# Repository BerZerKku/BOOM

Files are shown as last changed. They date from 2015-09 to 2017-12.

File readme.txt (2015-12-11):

Boom

BOOM-LCD_01v1
Плата индикации для проекта BOOM.

BOOM-MCU_01v1
Плата управления для проекта BOOM.
Разъем X2 установлен не с той стороны платы, пока запаян шлейф. 
Нужны доработки по входам Wire (подтяжка к +5В и кондер на землю).
Кнопки S1,S2 установлены выводные на стороне TOP.
Почему-то не совпали номера сегментов при выводе значений на индикатор, надо проверить!

PHONE-CODE_01v1
Плата управления для телефона.
Питание на плате появляется при снятой трубке.
Вводится номер. Если верный, то подается сигнал управления (замыкание на змелю, 2А, 30В). Сигнал управления подается 1 минуту или до момента возвращения трубки на место. Если номер не верный, то нужно положить трубку и снять заново.

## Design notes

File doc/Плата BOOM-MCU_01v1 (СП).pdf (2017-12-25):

№ | Наименование | Корпус | Кол. | Поз. | Примечание
5 | Лист | № докум. | Подп. | Дата | BOOM-MCU_01v1 Изм
Разраб. | Щеблыкин М.В | | | Плата BOOM-MCU_01v1 Спецификация | Лит. | Лист | Листов
Провер. | | | | | | 1 | 3

Н.контр.
Утв.
1 | Сборочный чертеж
| BOOM-MCU_01v1 rev.0 | 1

ДЕТАЛИ
3 | Плата печатная
| BOOM-MCU_01v1 | 1

ПРОЧИЕ ИЗДЕЛИЯ

Диоды

5 | MBR0540 | SOD123 | 3 | VD1,VD3,VD4 | N000274990
6 | P6SMB18CA | DO-214AA | 2 | VD7,VD8 | О01301
7 | P6SMB300CA | DO-214AA | 1 | VD6 | О16069
9 | SM6T30CA | DO-214AA | 1 | VD5 | N000379801
11 | STPS160U STM | DO-214AA | 1 | VD2 | N000388908
15 | Индуктивность SCDS127T-331M-N 330u 0.95A YAGEO | SMD_2 | 1 | L1 | промка
16 | Индуктивность LQH43CN100K 650mA 10uH 10% 1812 MURATA | SMD_2 | 1 | L2*

Конденсаторы

19 | 0805 NP0 50V 22pF 5% | 0805 | 2 | C8,C9 | О05537
20 | 0805 X7R 50V 0.01uF 10% | 0805 | 3 | C13*,C14*,C15* | О03660
21 | 1206 X7R 50V 0.1uF 10% | 1206 | 6 | C1,C3-C5,C7,C16* | О01782
23 | 1206 X7R 50V 1uF 10% | 1206 | 2 | C10,C12,C17* | О12148
25 | 1206 X7R 25V 10uF 10% | 1206 | 1 | С2 | N000381052
27 | тантал 10V 220uF 10% X | X | 2 | C6*,C11 | N000309836
31 | Кварцевый резонатор KX-3H
16.0MHz HC-49/S GEYER | 2 pins | 1 | ZQ1 | О00314

| | | | | BOOM-MCU_01v1 | Лист
5 | | | | | | 2
Изм | Лист | № докум. | Подп. | Дата
35 | Крышка 255-600 WAGO | 3 | N000197881

Микросхемы

39 | AT90USB162-16AU ATMEL | TQFP32 | 1 | DD1 | ОS1761
41 | G3VM-351E OMRON | SMD_6 | 2 | U2,U3 | N000367341
43 | HCPL-817-300E AVAGO | SMD_4 | 1 | U1 | N000389177
45 | LM2574M-5.0 TI | SOIC_14 | 1 | DA1 | О05934
49 | Переключатель SWT-20-4,3 | 4 pins | 2 | S1*,S2* | О00616
53 | Предохранитель MF-SM75/60
самовосст. BOURNS | SMD_2 | 1 | F1 | N000428722

Разъемы

57 | 255–401 Gray WAGO | 2 pins | 7 | J2,J4,J6,J8,J9,J11,J13 | N000246172
59 | 255–746 Orange WAGO | 2 pins | 7 | J1,J3,J5,J7,J10,J12,J14 | N000246339
61 | PBD-20 | 20 pins | 1 | X2 | О00425 Не устанавл.
63 | USB A 18 вилка SMT | 6 pins | 1 | X1 | N000334100

Резисторы

65 | 0805 3.6 5% | 0805 | 3 | R3* | О00024
65 | 0805 10K 5% | 0805 | 3 | R31*,R32*,R33* | О00029
67 | 1206 24 5% (1206 24.9 1%) | 1206 | 2 | R1,R2 | N000388735 (О02250)
69 | 1206 100 5% | 1206 | 13 | R5-R16,R18 | О01268
71 | 1206 510 5% | 1206 | 2 | R19,R20 | О07691
73 | 1206 1K 5% | 1206 | 8 | R17,R21,R24-29 | О01259
75 | 1206 10K 5% | 1206 | 3 | R22,R23,R30 | О08066
79 | Феррит BLM31PG601SN1 MURATA | 1206 | 2 | FB1,FB2 | N000307145
| | | | * - доработка

| | | | | BOOM-MCU_01v1 | Лист
5 | | | | | | 3
Изм | Лист | № докум. | Подп. | Дата

Лист регистрции изменений СП
№ Изм. | № замененных (измененных) страниц | Дата ревизии | Краткое содержание и причина внесения изменений | Примечание
0 | вновь | 16.09.2015
1 | 1-2 | 11.12.2015 | Добавлены поз.20 и 65. Изменена поз.49 на выводную кнопку. Поз.61 не устанавливать.
2 | 1-2 | 12.02.2016 | Добавлена поз.6, туда перенесены 2 диода из поз.7.
3 | 1 | 17.03.2016 | В поз.21 добавлен С16*.
4 | 1-2 | 22.12.2017 | В поз.26 добавлен С6*. Поз.65 изменена на 3.6 Ом.
5 | 1 | 25.12.2017 | В поз.23 добавлен С17*. Добавлена поз.16 (L2*).

Исполнения:

Лист регистрции изменений СБ
№ Изм. | № замененных (измененных) страниц | Дата ревизии | Краткое содержание и причина внесения изменений | Примечание
0 | вновь | 16.09.2015

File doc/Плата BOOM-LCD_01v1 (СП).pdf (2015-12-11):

№ | Наименование | Корпус | Кол. | Поз. | Примечание
1 | Лист | № докум. | Подп. | Дата | BOOM-LCD_01v1 Изм
Разраб. | Щеблыкин М.В | | | Плата BOOM-LCD_01v1 Спецификация | Лит. | Лист | Листов
Провер. | | | | | | 1 | 2

Н.контр.
Утв.
1 | Сборочный чертеж
| BOOM-LCD_01v1 rev.0 | 1

ДЕТАЛИ
3 | Плата печатная
| BOOM-LCD_01v1 | 1

ПРОЧИЕ ИЗДЕЛИЯ

Диоды

5 | FYL-5013PURD1C-60 KINGBRIGHT | 2 pins | 2 | VD1,VD2 | N000375522
7 | SA23-11SRWA KINGBRIGHT | 10 pins | 4 | HG1-HG4 | промка

Конденсаторы

11 | 1206 X7R 50V 0.1uF 10% | 1206 | 1 | C1 | О01782
13 | 1206 X7R 25V 10uF 10% | 1206 | 1 | С2 | N000381052
| Микросхемы
17 | G3VM-351E OMRON | SMD_6 | 4 | U1-U4 | N000367341
19 | ULN2803ADW TI | SOIC_18 | 1 | DD1 | О06632
23 | Разъем IDC-20M вилка SMD | SMD_20 | 1 | X1 | промка

Резисторы

27 | 1206 100 5% | 1206 | 7 | R7-R13 | О01268
29 | 1206 510 5% | 1206 | 4 | R14-R17 | О07691
31 | 1206 2K 5% | 1206 | 1 | R6 | О01260

| | | | | BOOM-LCD_01v1 | Лист
1 | | | | | | 2
Изм | Лист | № докум. | Подп. | Дата

Лист регистрции изменений СП
№ Изм. | № замененных (измененных) страниц | Дата ревизии | Краткое содержание и причина внесения изменений | Примечание
0 | вновь | 16.09.2015
1 | 1 | 11.12.2015 | Поз.27 изменена на 100 Ом Поз.31 изменена на 2 кОм.

Исполнения:

Лист регистрции изменений СБ
№ Изм. | № замененных (измененных) страниц | Дата ревизии | Краткое содержание и причина внесения изменений | Примечание
0 | вновь | 16.09.2015

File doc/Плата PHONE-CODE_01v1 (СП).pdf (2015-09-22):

№ | Наименование | Корпус | Кол. | Поз. | Примечание
0 | Лист | № докум. | Подп. | Дата | PHONE-CODE_01v1 Изм
Разраб. | Щеблыкин М.В | | | Плата PHONE-CODE_01v1 Спецификация | Лит. | Лист | Листов
Провер. | | | | | | 1 | 3

Н.контр.
Утв.
1 | Сборочный чертеж
| PHONE-CODE_01v1 rev.0 | 1

ДЕТАЛИ
3 | Плата печатная
| PHOONE-CODE_01v1 | 1

ПРОЧИЕ ИЗДЕЛИЯ

Диоды

5 | FYL-5013PURD1C-60 KINGBRIGHT | 2 pins | 1 | VD4 | N000375522
7 | LL4148 | SOD80 | 2 | VD1,VD2 | ОN5384
9 | MBR0540 | SOD123 | 1 | VD3 | N000274990
11 | SM6T30A | DO-214AA | 1 | VD9 | N000398718
13 | SM6T30CA | DO-214AA | 1 | VD7 | N000379801
15 | SM6T6V8CA | DO-214AA | 1 | VD6 | О08193

Конденсаторы

19 | 1206 X7R 50V 0.1uF 10% | 1206 | 6 | C1,C2,C4,C6-C8 | О01782
21 | 1206 X7R 50V 1uF 10% | 1206 | 1 | C5 | О12148
23 | 1206 X7R 25V 10uF 10% | 1206 | 1 | С3 | N000381052
27 | Крышка 255-600 WAGO | 1 | N000197881

Микросхемы

31 | ATMega8-16AU ATMEL | TQFP32 | 1 | DD1 | О14110
33 | LM317EMP | SOT-223 | 1 | DA1 | О01278

| | | | | PHONE-CODE_01v1 | Лист
0 | | | | | | 2
Изм | Лист | № докум. | Подп. | Дата
37 | Переключатель SmWDL-02 | SMD_4 | 1 | SW1 | О01270

Разъемы

41 | 255–401 Gray WAGO | 2 pins | 4 | J1,J2,J5,J8 | N000246172
43 | 255–746 Orange WAGO | 2 pins | 3 | J3,J4,J7 | N000246339

Резисторы

47 | 1206 100 5% | 1206 | 1 | R13 | О01268
49 | 1206 510 5% | 1206 | 1 | R2 | О07691
51 | 1206 1K 5% | 1206 | 4 | R4,R9-R11 | О01259
53 | 1206 2K 5% | 1206 | 1 | R3 | О01260
55 | 1206 10K 5% | 1206 | 4 | R1,R6,R7,R14 | О08066
57 | 2010 56 5% | 2010 | 1 | R16 | N000251760
61 | Транзистор IRLML0060 IR | SOT23-3 | 1 | VT1 | N000368051

| | | | | PHONE-CODE_01v1 | Лист
0 | | | | | | 3
Изм | Лист | № докум. | Подп. | Дата

Лист регистрции изменений СП
№ Изм. | № замененных (измененных) страниц | Дата ревизии | Краткое содержание и причина внесения изменений | Примечание
0 | вновь | 22.09.2015

Исполнения:

Лист регистрции изменений СБ
№ Изм. | № замененных (измененных) страниц | Дата ревизии | Краткое содержание и причина внесения изменений | Примечание
0 | вновь | 22.09.2015

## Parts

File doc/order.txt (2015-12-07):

Используется у нас:
Название					Код 		Шт.		Наличие

Диоды
FYL-5013PURD1C-60  			N000375522	3		есть на складе
LL4148						ОN5384    	2 		есть на складе
MBR0540						N000274990	4 		есть на складе
P6SMB300CA					О16069		3 		есть на складе
SM6T30A						N000398718	1 		есть на складе
SM6T30CA					N000379801	2 		есть на складе
SM6T6V8CA					О08193 		1 		есть на складе
STPS160U					N000388908	1 		есть на складе

Индуктивности
SCDS127T-331M-N				NO			1 		заказать 10шт. (есть в промке) 

Кварцы
KX-3H 16.0MHz HC-49/S Geyer	О00314 		1 		есть на складе

Конденсаторы
0805 NP0 50V 22pF 5%		О05537    	2 		есть на складе
1206 X7R 50V 0.1uF 10%		О01782		12		есть на складе
1206 X7R 50V 1uF 10%		О12148		3 		есть на складе
1206 X7R 25V 10uF 10%		N000381052	2   	есть на складе
тантал 10V 220uF 10% X 		N000309836	1 		заказать 10 шт. (есть в промке T491X227K010AT)

Крышка 255-600 WAGO			N000197881	4 		есть на складе

Микросхемы		
AT90USB162-16AU ATMEL		ОS1761		1 		есть у меня 3шт, заказать 5шт.
ATMega8-16AU				О14110  	1 		есть на складе
G3VM-351E  					000367341	6 		есть на складе  
HCPL-817-300E				N000389177	1 		есть на складе
LM2574M-5.0 				О05934 		1 		заказать 10шт. (есть в промке)
LM317EMP					О01278 		1 		есть на складе
ULN2803ADW					О06632		1 		есть на складе

Переключатели 
DTSMW-2.0S					N000261668 	2 		заказать 20шт. (есть в промке)
SmWDL-02					О01270 		1 		на складе нет	

Предохранитель MF-SM75/60 	N000428722 	1 		заказать 20шт.

Разъемы
255–401 Gray WAGO 			N000246172 	8 		есть на складе
255–746 Orange WAGO 		N000246339 	7 		есть на складе
IDC-20M вилка SMD			NO			1 		заказать 10шт. (есть в промке)
PBD-20 						О00425 		1 		есть на складе	
USB A 18 вилка SMT 			N000334100 	1 		есть у меня 3шт, заказать 5шт.

Резисторы
1206 24.9 1%				О02250     	2 		есть на складе
1206 100 5% 				О01268 		14 		есть на складе	
1206 200 5%					О06039		7 		есть на складе
1206 510 5% 				О07691		7 		есть на складе
1206 1K 5%					О01259		13 		есть на складе
1206 1.5K 5%				О01267     	1 		есть на складе
1206 10K 5%					О08066 		7 		есть на складе	
2010 100 5%					N000400359	1 		есть на складе

Транзистор IRLML0060 		N000368051 	1 		есть на складе

Феррит BLM31PG601SN1		N000307145	2 		есть на складе

Купить самому:
Щуп BANAN б/пайки Gold тип1   	30шт. - Узнать про гнезда на панель!
Разъем MDN-6J розетка на печатную плату (AUK) 5шт.
Индикатор SA23-11SRWA			4шт.

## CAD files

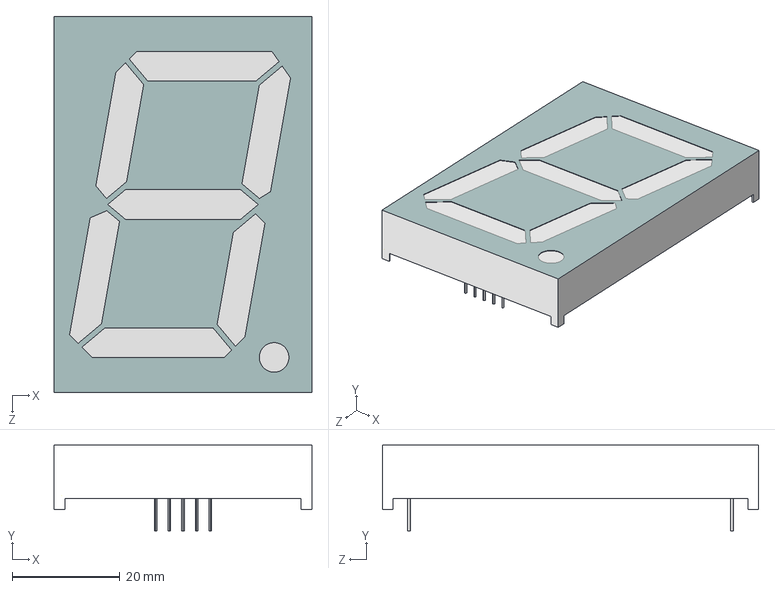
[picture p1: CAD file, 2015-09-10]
pcb-lcd/SA23-11.STEP
48.0 x 16.0 x 70.0 mm

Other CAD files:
doc/Плата BOOM_01v1 (СБ).dwg
doc/Плата BOOM-LCD_01v1 (СБ).dwg
doc/Плата BOOM-MCU_01v1 (СБ).dwg
doc/Плата PHONE-CODE_01v1 (СБ).dwg
pcb-lcd/dip254p6010x1200-10n.psm
pcb-lcd/soic127p1030x265-18n.psm
pcb-lcd/soic254p1000x1020-20n.psm
pcb-lcd/soic254p978x342-6m.psm
pcb-mcu/con_usb_a_male_smd.psm
pcb-mcu/indc12501250x800n.psm
pcb-mcu/qfp80p900x900x120-32n.psm
pcb-mcu/soic127p1032x265-14n.psm
pcb-phone/qfp80p900x900x120-32n.psm
pcb-phone/relay_32_21.psm
pcb-phone/soic254p978x342-6m.psm

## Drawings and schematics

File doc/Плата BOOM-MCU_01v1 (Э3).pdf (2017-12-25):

* - Доработка.

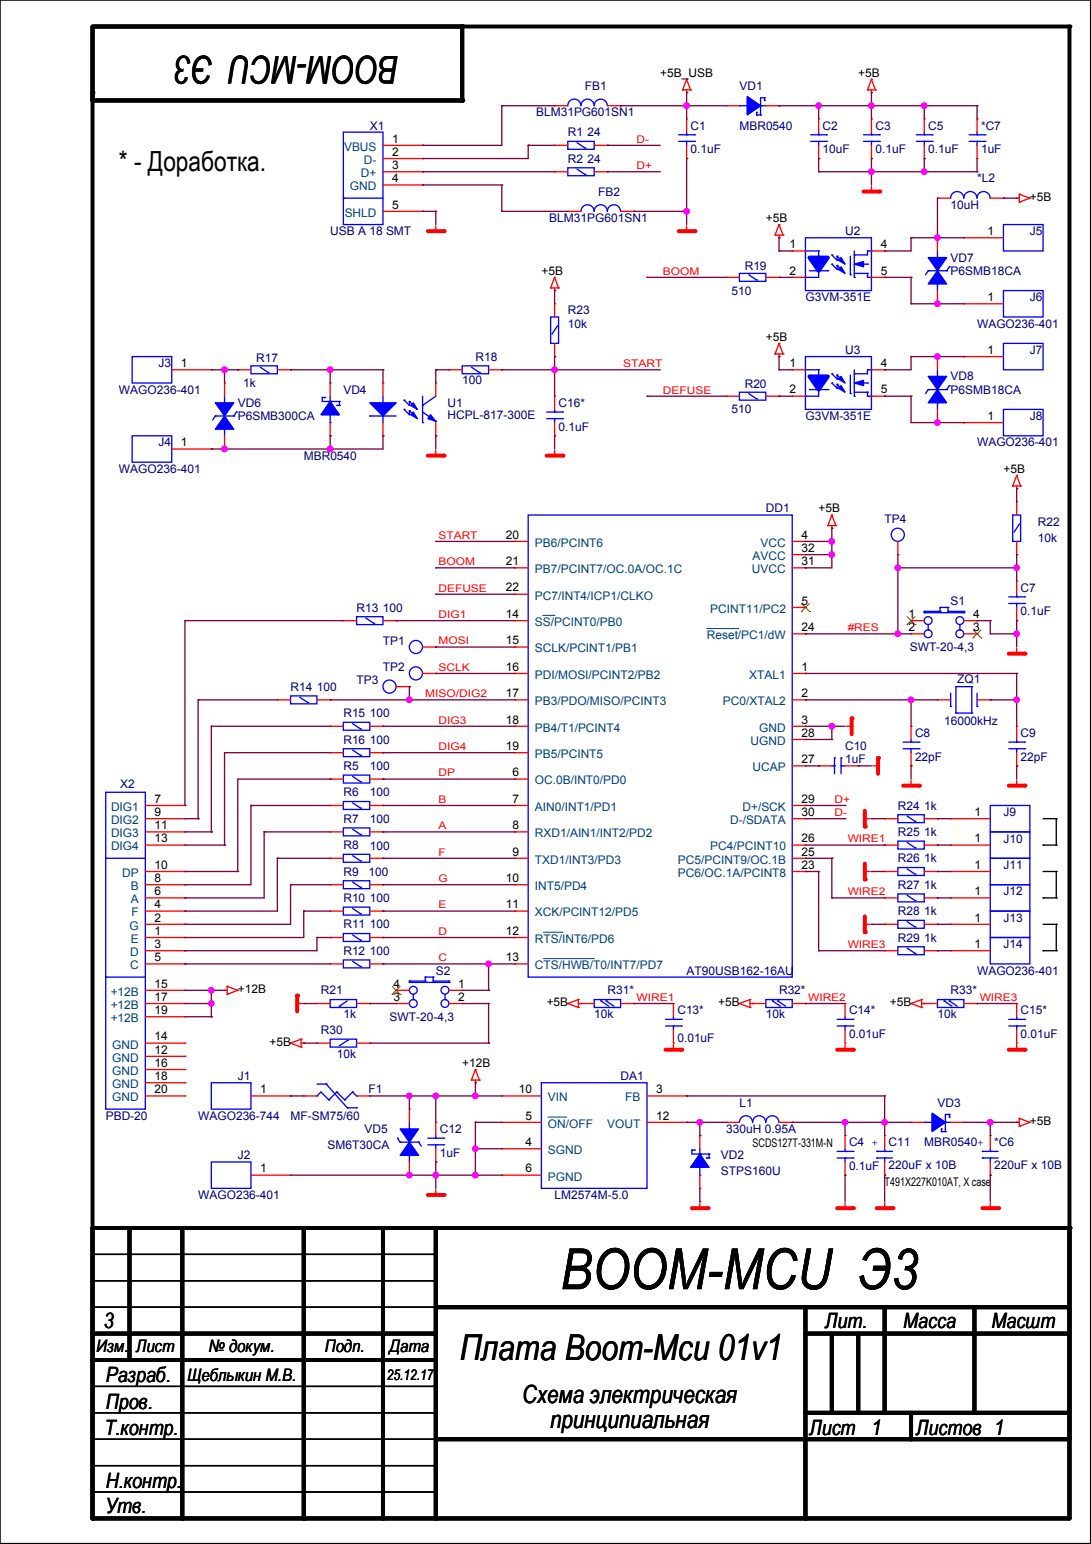
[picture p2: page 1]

BOOM-MCU Э3 BOOM-MCU Э3 BOOM-MCU Э3

3 | | | | | Плата Boom-Mcu 01v1 Плата Boom-Mcu 01v1 Плата Boom-Mcu 01v1 Схема электрическая Схема электрическая Схема электрическая | Лит. | Масса Масса Масса | Масшт Масшт Масшт
Изм. Изм. Изм. | Лист Лист Лист | № докум. № докум. № докум. | Подп. Подп. Подп. | Дата Дата Дата
Разраб. Разраб. Разраб. | | Щеблыкин М.В. Щеблыкин М.В. Щеблыкин М.В. | | 25.12.17 25.12.17 25.12.17
Пров. Пров. Пров.
принципиальная Т.контр. принципиальная Т.контр. принципиальная Т.контр. | Лист Лист Лист 1 1 1 1 1 1 | Листов Листов Листов

Н.контр. Н.контр. Н.контр.
Утв. Утв. Утв.

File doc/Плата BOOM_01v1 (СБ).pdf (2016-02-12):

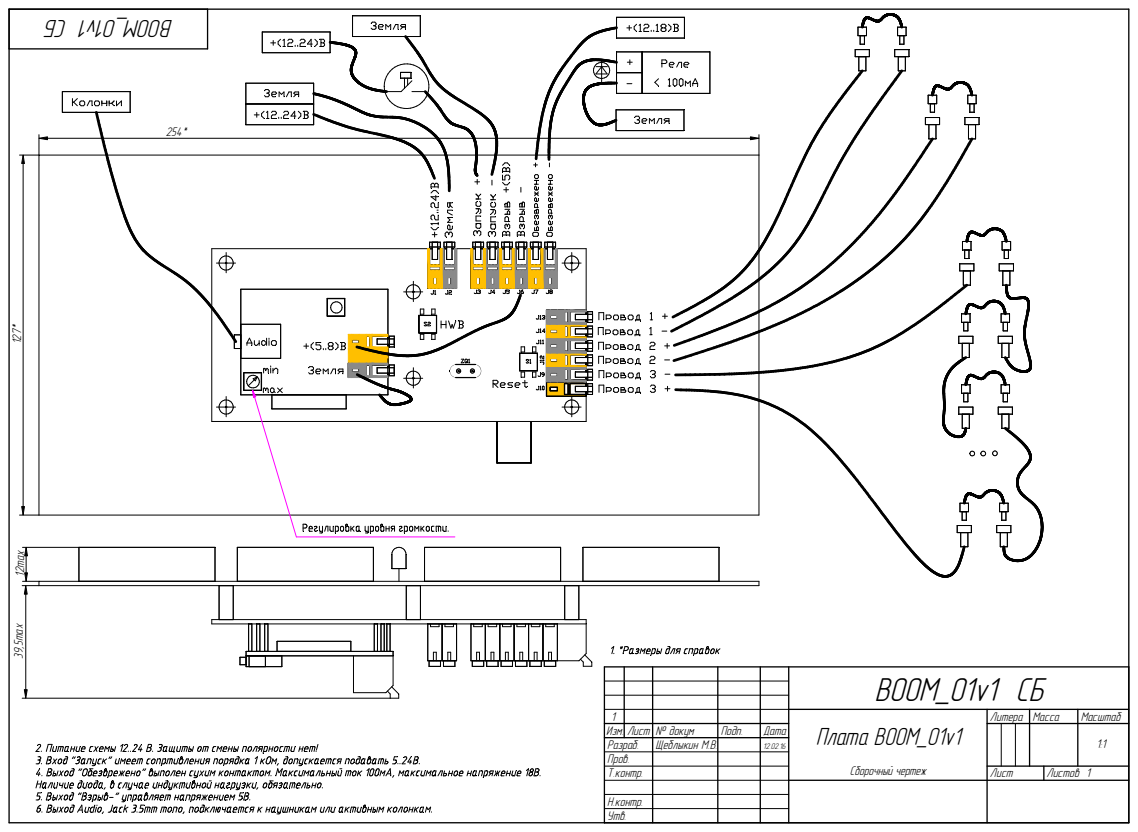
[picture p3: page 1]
12max 39,5max

BOOM_01v1 ÑÁ

1 | | | | Ïëàòà BOOM_01v1 Ñáîðî÷íûé ÷åðòåæ | Ëèòåðà | Ìàññà | Ìàñøòàá
Èçì. Ëèñò | № äîêóì | Ïîäï. | Äàòà 12.02.16 | | | | | 1:1
Ðàçðàá. | Ùåáëûêèí Ì.Â.
Ïðîâ.
Ò.êîíòð. | | | | Ëèñò | Ëèñòîâ 1

Í.êîíòð.
Óòâ.

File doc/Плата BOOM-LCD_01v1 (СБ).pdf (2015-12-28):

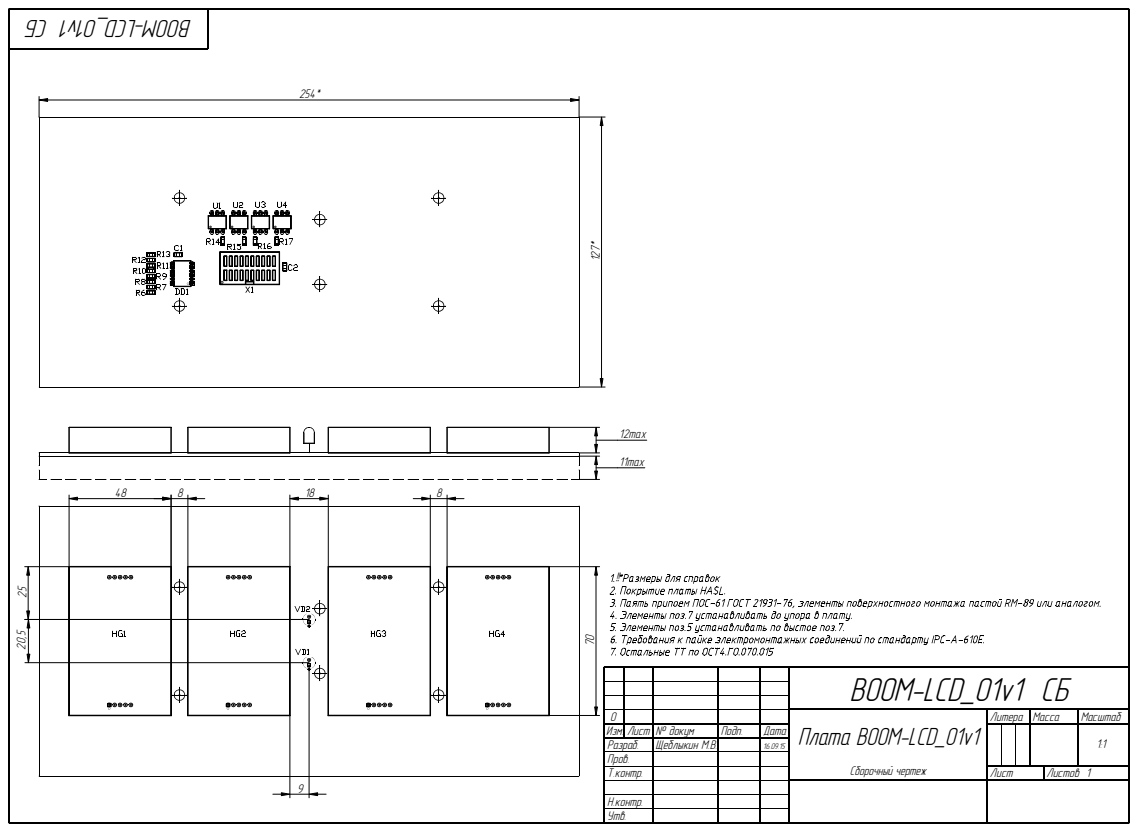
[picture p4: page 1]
Ëèñòîâ 1; Ìàññà; Ìàñøòàá; Ïîäï.; Äàòà; Óòâ.; Í.êîíòð.; Ò.êîíòð.; Ïðîâ.; Ðàçðàá.; Èçì. Ëèñò; Ùåáëûêèí Ì.Â.; № äîêóì; Ëèñò; Ëèòåðà; Ïëàòà BOOM-LCD_01v1; BOOM-LCD_01v1 ÑÁ; 11max; 12max

Ñáîðî÷íûé ÷åðòåæ

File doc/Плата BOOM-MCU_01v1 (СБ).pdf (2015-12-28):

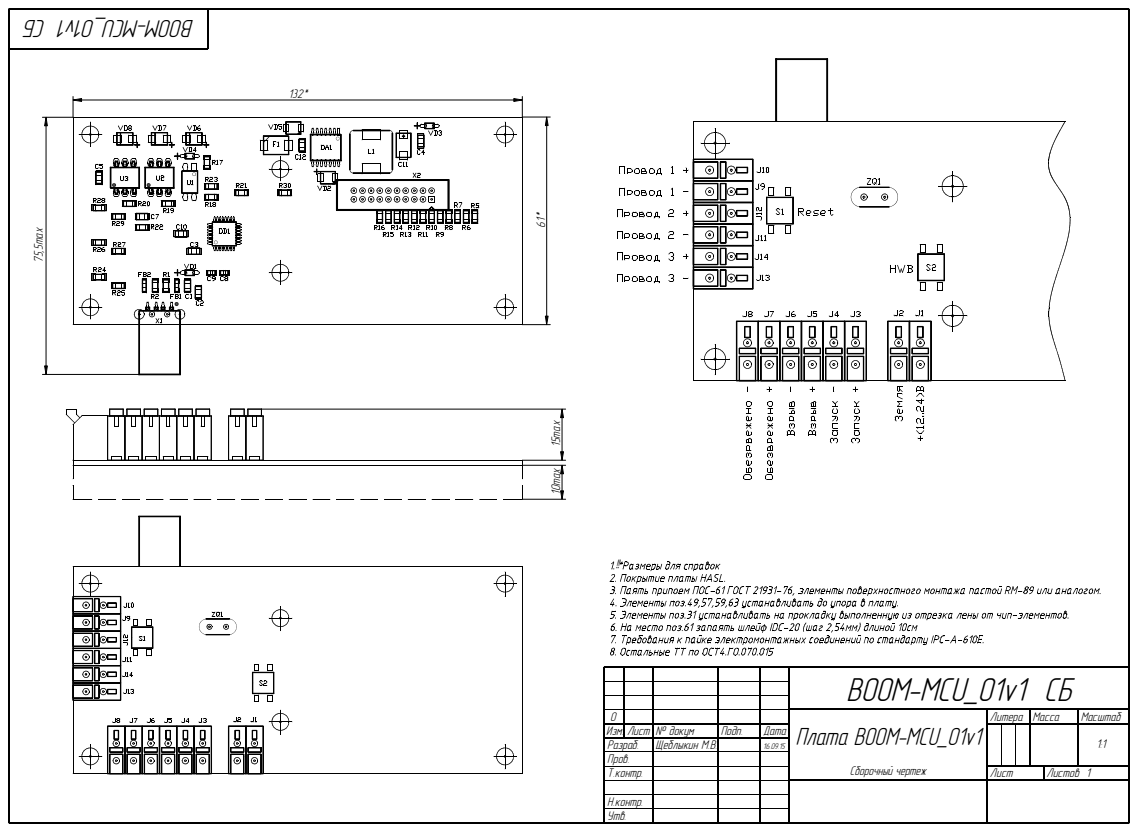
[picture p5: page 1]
Ëèñòîâ 1; Ìàññà; Ìàñøòàá; Ïîäï.; Äàòà; Óòâ.; Í.êîíòð.; Ò.êîíòð.; Ïðîâ.; Ðàçðàá.; Èçì. Ëèñò; Ùåáëûêèí Ì.Â.; № äîêóì; Ëèñò; Ëèòåðà; Ïëàòà BOOM-MCU_01v1; BOOM-MCU_01v1 ÑÁ; 10max 15max; 75,5max

Ñáîðî÷íûé ÷åðòåæ

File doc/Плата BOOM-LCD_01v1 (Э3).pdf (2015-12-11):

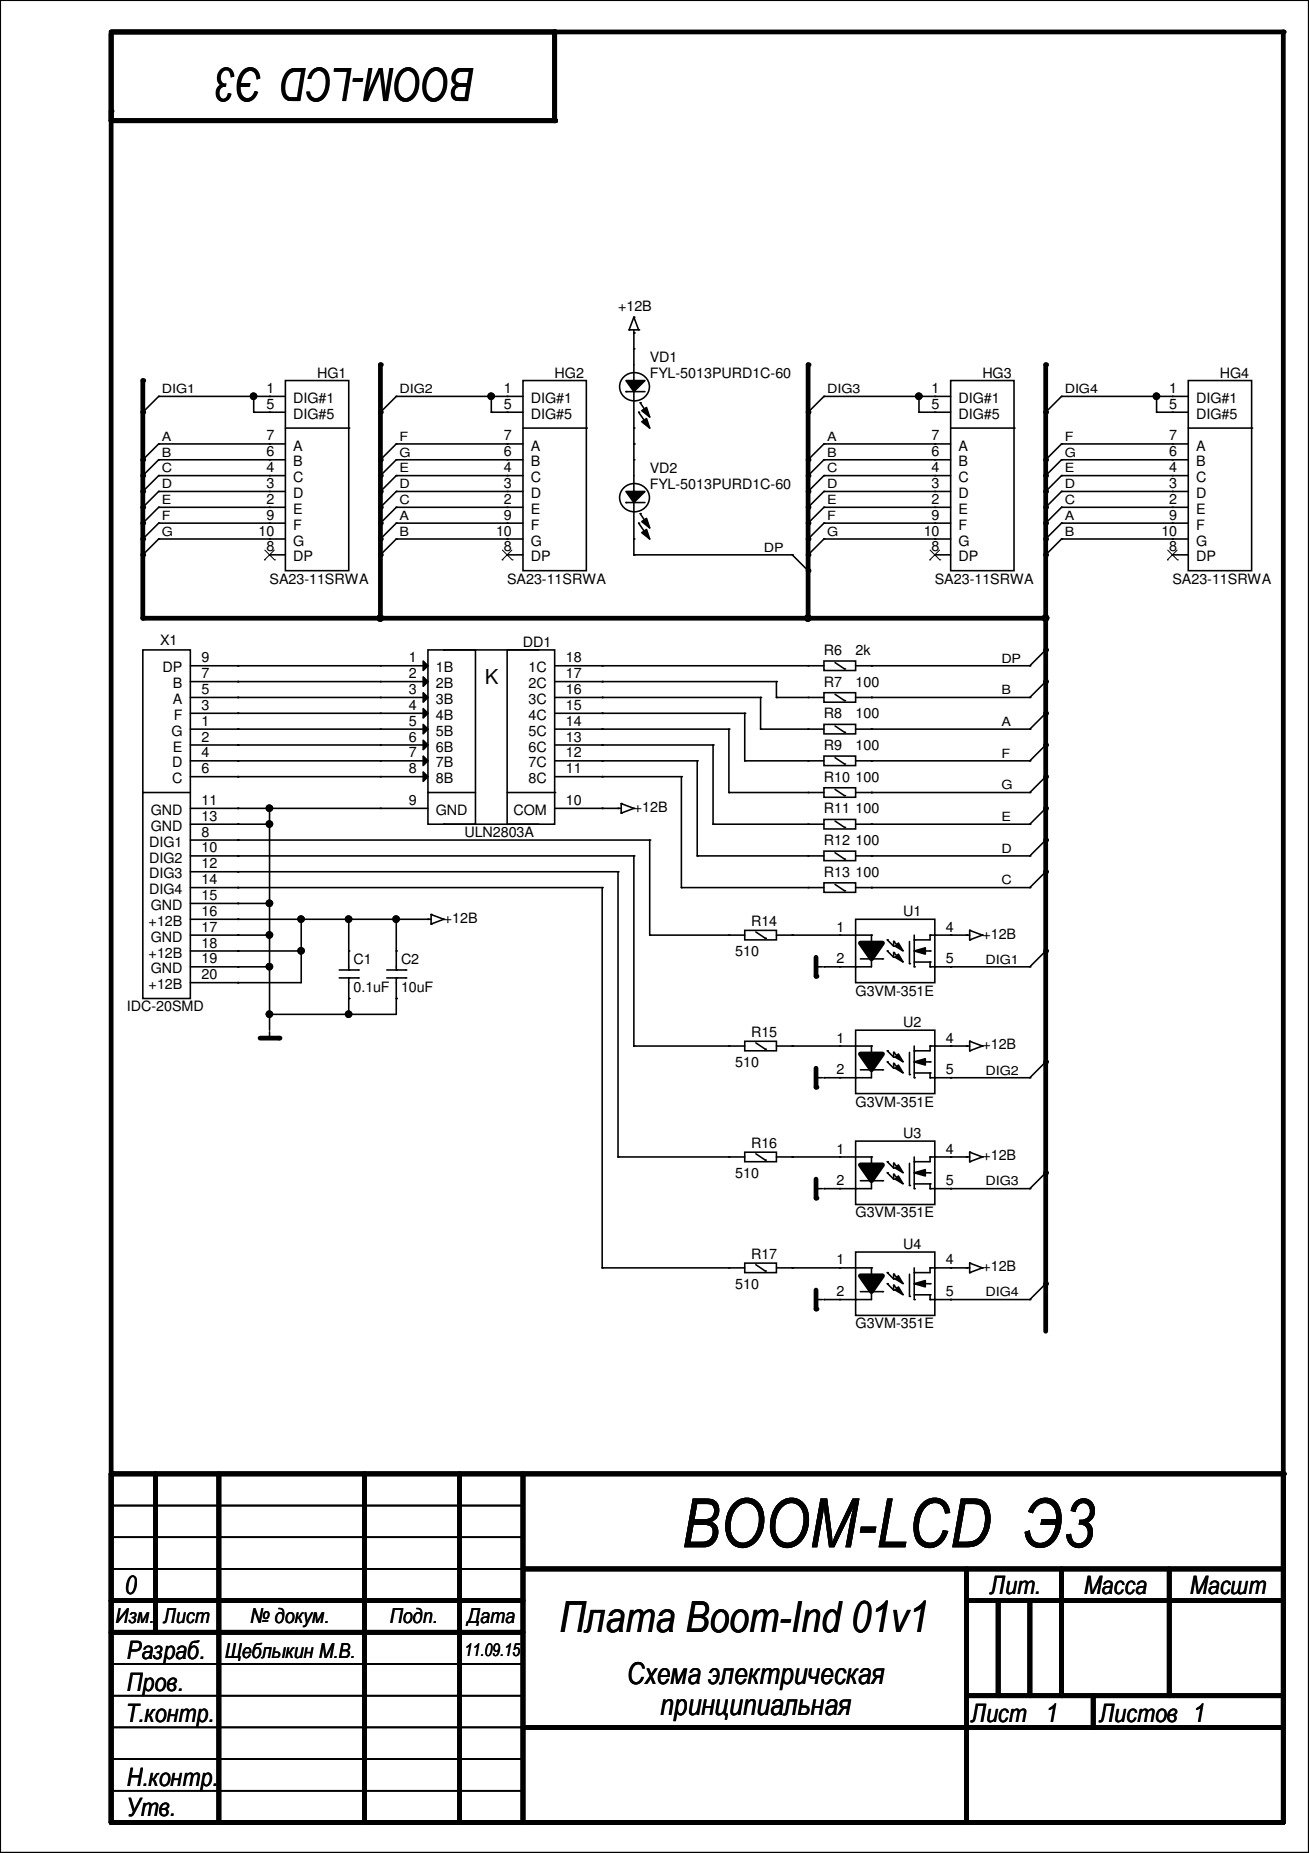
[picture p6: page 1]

BOOM-LCD Э3 BOOM-LCD Э3 BOOM-LCD Э3

0 | | | | | Плата Boom-Ind 01v1 Плата Boom-Ind 01v1 Плата Boom-Ind 01v1 Схема электрическая Схема электрическая Схема электрическая | Лит. | Масса Масса Масса | Масшт Масшт Масшт
Изм. Изм. Изм. | Лист Лист Лист | № докум. № докум. № докум. | Подп. Подп. Подп. | Дата Дата Дата
Разраб. Разраб. Разраб. | | Щеблыкин М.В. Щеблыкин М.В. Щеблыкин М.В. | | 11.09.15 11.09.15 11.09.15
Пров. Пров. Пров.
принципиальная Т.контр. принципиальная Т.контр. принципиальная Т.контр. | Лист Лист Лист 1 1 1 1 1 1 | Листов Листов Листов

Н.контр. Н.контр. Н.контр.
Утв. Утв. Утв.

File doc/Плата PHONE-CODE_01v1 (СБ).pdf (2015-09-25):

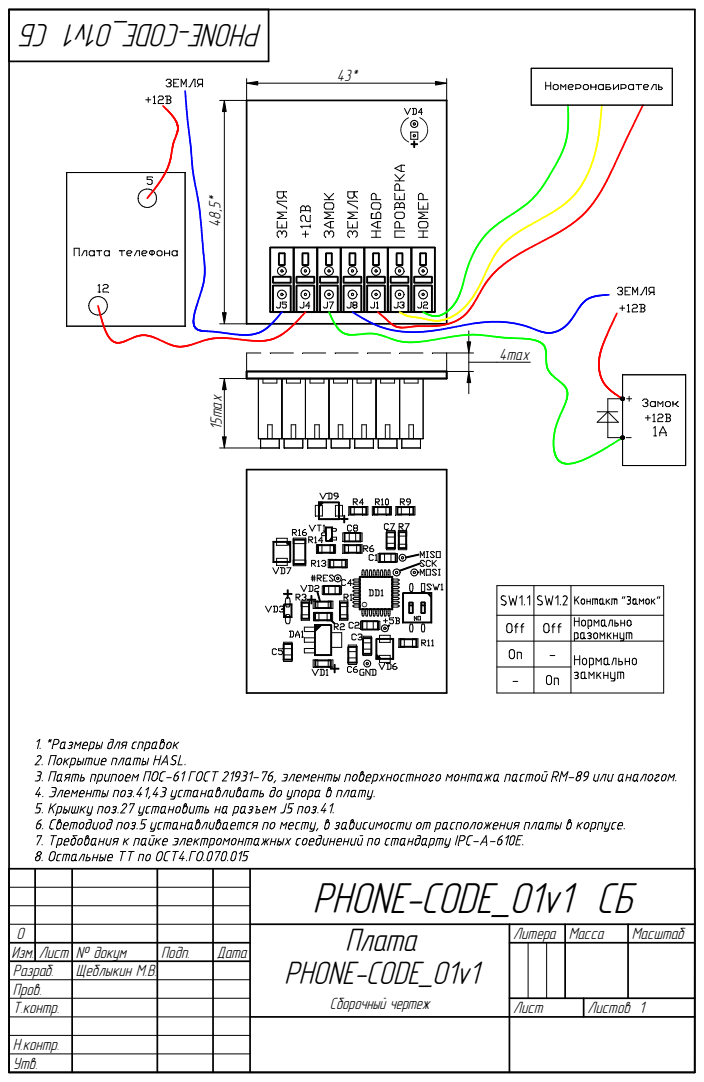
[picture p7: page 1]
4max; 15max

PHONE-CODE_01v1 ÑÁ

0 | | | | Ïëàòà PHONE-CODE_01v1 Ñáîðî÷íûé ÷åðòåæ | Ëèòåðà | Ìàññà | Ìàñøòàá
Èçì. | № äîêóì | Ïîäï. | Äàòà Ëèñò
Ðàçðàá. | Ùåáëûêèí Ì.Â.
Ïðîâ.
Ò.êîíòð. | | | | Ëèñò | Ëèñòîâ 1

Í.êîíòð.
Óòâ.

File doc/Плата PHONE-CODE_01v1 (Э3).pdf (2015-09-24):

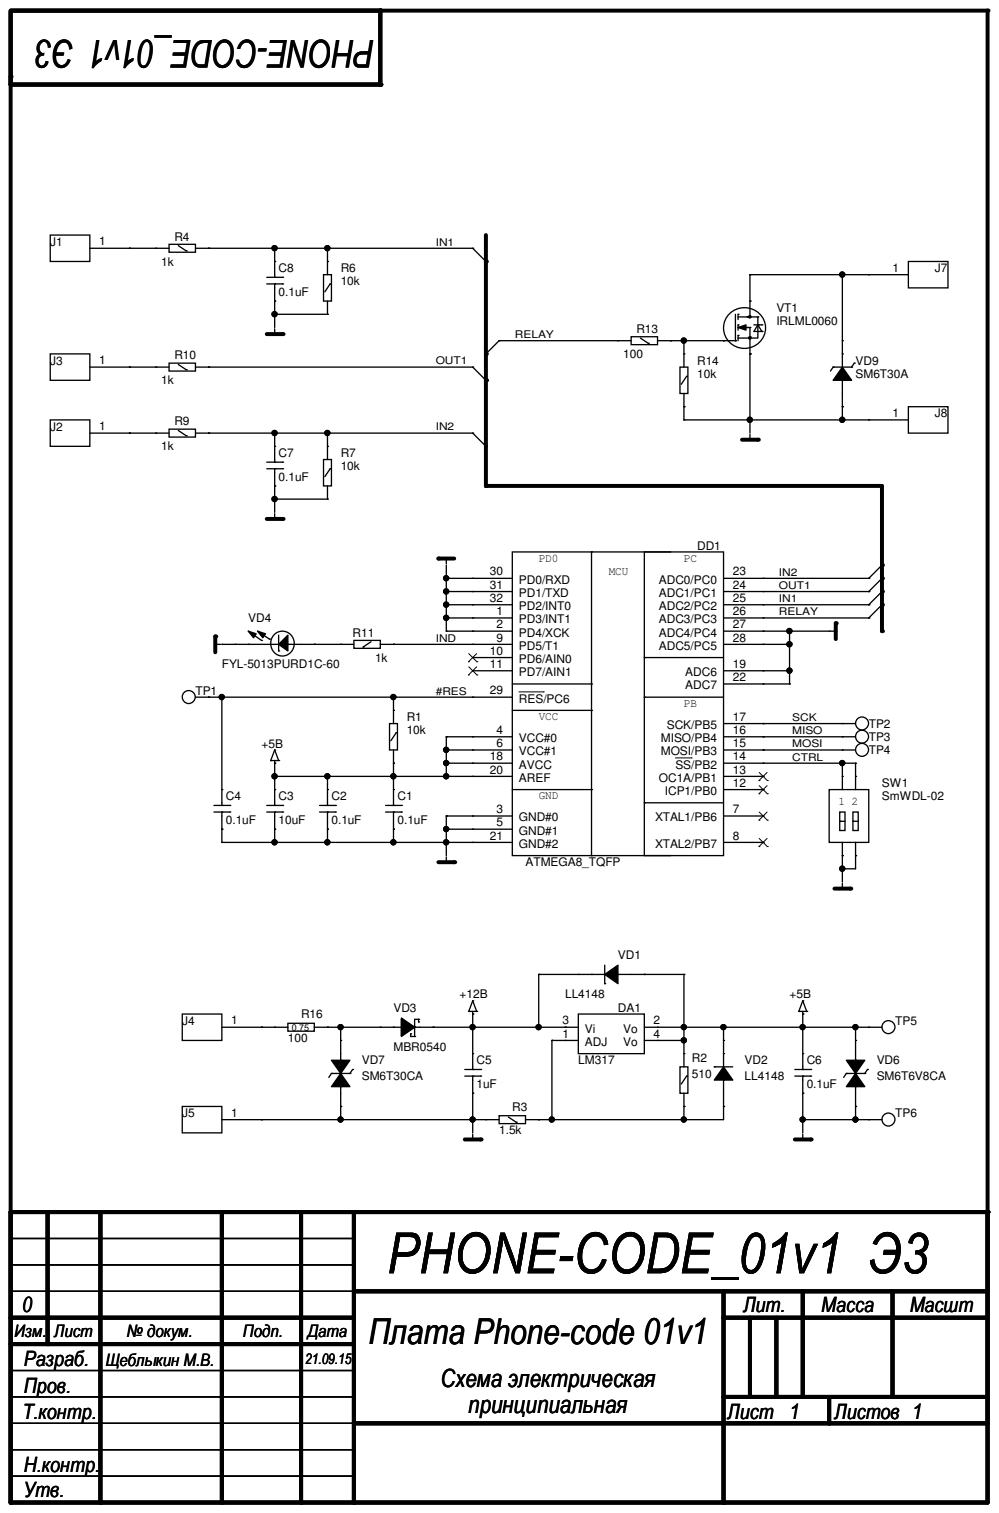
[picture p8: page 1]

PHONE-CODE_01v1 Э3 PHONE-CODE_01v1 Э3 PHONE-CODE_01v1 Э3

0 | | | | | Плата Phone-code 01v1 Плата Phone-code 01v1 Плата Phone-code 01v1 Схема электрическая Схема электрическая Схема электрическая | Лит. | Масса Масса Масса | Масшт Масшт Масшт
Изм. Изм. Изм. | Лист Лист Лист | № докум. № докум. № докум. | Подп. Подп. Подп. | Дата Дата Дата
Разраб. Разраб. Разраб. | | Щеблыкин М.В. Щеблыкин М.В. Щеблыкин М.В. | | 21.09.15 21.09.15 21.09.15
Пров. Пров. Пров.
принципиальная Т.контр. принципиальная Т.контр. принципиальная Т.контр. | Лист Лист Лист 1 1 1 1 1 1 | Листов Листов Листов

Н.контр. Н.контр. Н.контр.
Утв. Утв. Утв.

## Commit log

2015-09-10 Платы для проекта BOOM.
    [BOOM-LCD_01v1.DSN, BOOM-LCD_01v1.brd, BOOM-MCU_01v1.DSN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]
2015-09-10 Изменена схема управления. Перекинута часть ножек. Изменено расположение элементов на плате. Добавлены переключатели и клеммники.
    [BOOM-MCU_01v1.DSN, BOOM-MCU_01v1.brd, qfp80p900x900x120-32n.psm]
2015-09-11 Добавлен резистор подтяжки к +5В на 13 ножку МК H\W\B\. Немного перерисована схема. Доделана разводка.
    [BOOM-MCU_01v1.DSN, BOOM-MCU_01v1.brd]
2015-09-11 Сделано сглаживание линий.
    [BOOM-MCU_01v1.brd]
2015-09-11 Добавлена защита по питанию и для дискретных входов/выходов. Доделана разводка.
    [BOOM-MCU_01v1.DSN, BOOM-MCU_01v1.brd, art_param.txt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]
2015-09-17 Добавлена документация на платы.
    [BOOM-MCU_01v1.DSN]
2015-09-21 Добавлена схема для кодового замка. На документации исправлены штампы.
    [BOOM-LCD_01v1.DSN, BOOM-MCU_01v1.DSN, PHODE-CODE_01v1.DSN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]
2015-09-22 Сделана разводка кодового замка.
    [PHODE-CODE_01v1.DSN, PHONE-CODE_01v1.brd]
2015-09-22 Добавлена документация и герберы на платы PHONE-CODE_01v1. Супрессор 6v8 заменен на двуполярный. В СП BOOM-* исправлены штампы. Обновлен список используемых элементов order.txt.
    [PHODE-CODE_01v1.DSN, PHONE-CODE_01v1.brd, art_param.txt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]
2015-09-24 Добавлен СБ для платы PHONE-CODE_01v1. На этой же плате измененя R3 с 2к на 1.5к, R16 с 56 на 100.
    [PHODE-CODE_01v1.DSN, PHONE-CODE_01v1.brd, Плата PHONE-CODE_01v1 (СБ).dwg]
2015-09-25 Исправлены названия контактов разъема на СБ для PHONE-CODE_01v1.
    [Плата PHONE-CODE_01v1 (СБ).dwg]
2015-09-25 На СБ для PHONE_CODE_01v1 добавлена схема подключения проводов.
    [Плата PHONE-CODE_01v1 (СБ).dwg]
2015-12-07 Убран "лишний" полигон, для облегчения печати.
    [BOOM-LCD_01v1.brd]
2015-12-11 На плате BOOM-MCU_01v1 добавлены резисторы подтяжки 10кОм и фильтрующий конденсатор 0,01мкФ на входы Wire1..3. На плате BOOM-LCD_01v1 для увеличения яркости индикаторов уменьшены сопротивления с 200 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
    [BOOM-LCD_01v1.DSN, BOOM-MCU_01v1.DSN]
2015-12-11 Добавлены сборочные чертежи на платы BOOM-MCU_01v1 и BOOM-LCD_01v1. На схеме BOOM-MCU_01v1 изменено название кнопки.
    [BOOM-LCD_01v1.brd, BOOM-MCU_01v1.DSN, BOOM-MCU_01v1.brd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]
2015-12-28 Добавлен сборочник для BOOM_01v1. С имеющихся убрана надпись "Прософт-Системы".
    [Плата BOOM-LCD_01v1 (СБ).dwg, Плата BOOM-MCU_01v1 (СБ).dwg, Плата BOOM_01v1 (СБ).dwg]
2015-12-28 Сборочник BOOM_01v1 распечатан в цвете.
    [Плата BOOM_01v1 (СБ).dwg]
2016-02-12 На плате BOOM-MCU_01v1 добавлен резистор 1Ом с +5В на клемму "Взрыв +". На сборке самой бомбы добавлена плата музыки и ее подключение.
    [BOOM-MCU_01v1.DSN, Плата BOOM_01v1 (СБ).dwg]
2016-03-17 Проблема: если бомба срабатывала по окончанию времени происходил автоматический перезапуск. -> По входу запуска бомбы добавлен фильтрующий конденсатор 0,1мкф.
    [BOOM-MCU_01v1.DSN]
2017-12-22 На плате BOOM-MCU_01v1 добавлен конденсатор 220мкФ по питанию. Иначе при запуске музыкальной платы происходила просадка напряжения и МК перезагружался.
    [BOOM-MCU_01v1.DSN]
2017-12-25 На плате BOOM-MCU_01v1 добавлен конденсатор 1мкФ по питанию МК и заменен резистор 3.6Ом на индуктивность 10мкФ. Иначе при запуске музыкальной платы происходила просадка напряжения и МК перезагружался.
    [BOOM-MCU_01v1.DSN]
